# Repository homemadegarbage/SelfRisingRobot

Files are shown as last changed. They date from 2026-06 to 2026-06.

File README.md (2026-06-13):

# SelfRisingRobot

2軸サーボの起き上がりロボット "poco" です。

MuJoCo上で強化学習した起き上がり動作を、M5Atom搭載の実機ロボットで動かします。

詳細記事:

https://homemadegarbage.com/rl13

## Contents

- `3Dmodel/` - 実機ロボット用の3Dプリントモデル
- `RL/` - MuJoCoモデル、強化学習環境、学習済みPPOモデル
- `Arduino/` - M5Atom用スケッチとエクスポート済みポリシーネットワーク

各フォルダ内の詳しい使い方は、それぞれのREADMEを参照してください。

## 3D Model

`3Dmodel/` には実機製作用のSTLファイルを置いています。

- `footP.stl`
- `arm1P.stl`
- `arm2P.stl`
- `armhornP.stl`

## Reinforcement Learning

`RL/` にはシミュレーションと学習済みモデルを置いています。

主な内容:

- MuJoCoモデル
- Gymnasium環境
- Stable-Baselines3 PPOの学習済みモデル
- 再生・評価スクリプト

## Arduino

`Arduino/` には実機制御用のM5Atomスケッチを置いています。

主な内容:

- `robo03.ino`
- `policy_network.h`

`policy_network.h` は学習済みポリシーをCヘッダ化したもので、M5Atom上で起き上がり動作を実行するために使います。

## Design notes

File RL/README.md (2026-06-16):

# robo1 getup PPO

MuJoCo上の2自由度ロボット `robo1` が倒れた姿勢から起き上がるための学習済みPPOモデルです。

## Files

このリポジトリを動かすために必要なファイルは以下です。

- `robo1_getup_ppo.zip` - Stable-Baselines3 PPOの学習済みモデル
- `robo1_env.py` - Gymnasium/MuJoCo環境
- `robo1.xml` - MuJoCoモデル定義
- `assets/` - `robo1.xml`が参照するSTLメッシュ
- `play_robo1_policy.py` - 学習済みモデルの再生
- `eval_robo1_policy.py` - 各倒立姿勢からの評価
- `search_all_getup.py` - 各倒れ姿勢ごとの起き上がり軌道候補を探索し、`getup_reference.py` に反映するための `BEST_SEQ` を出力
- `getup_reference.py` - 教師データ生成に使う、各倒れ姿勢ごとのサーボ目標角waypoint列
- `scripted_getup.py` - `getup_reference.py` に定義した起き上がり軌道をMuJoCo viewerで再生確認
- `pretrain_robo1_from_scripted.py` - `getup_reference.py` の軌道から観測と教師actionのペアを生成し、PPO方策を事前学習
- `train_robo1.py` - PPOによる追加学習
- `export_policy_header.py` - 学習済みモデルからArduino用Cヘッダを生成
- `requirements.txt` - Python依存パッケージ

## Setup

```powershell
python -m venv .venv
.\.venv\Scripts\Activate.ps1
pip install -r requirements.txt
```

## Play

```powershell
python play_robo1_policy.py
```

特定の初期姿勢から再生する場合:

```powershell
python play_robo1_policy.py --pose roll_pos
python play_robo1_policy.py --pose roll_neg
python play_robo1_policy.py --pose pitch_pos
python play_robo1_policy.py --pose pitch_neg
```

## Evaluate

```powershell
python eval_robo1_policy.py
```

## Training

`getup_reference.py` に定義した起き上がり教師データから初期方策を事前学習します。

起き上がり軌道を再探索する場合は、以下を実行します。

```powershell
python search_all_getup.py
```
出力された `BEST_SEQ` または `REFERENCE_CANDIDATES` の配列を
`getup_reference.py` の `getup_sequence_for_pose()` に反映します。

教師データから初期方策を事前学習

```powershell
python pretrain_robo1_from_scripted.py
```

これにより `robo1_getup_ppo.zip` が生成されます。

続けてPPOで追加学習します。

```powershell
python train_robo1.py --model-in robo1_getup_ppo.zip --timesteps 200000 --n-envs 6 --model-out robo1_getup_ppo
```

ゼロからPPO学習する場合は `--model-in` を省略します。

```powershell
python train_robo1.py --timesteps 200000 --n-envs 6 --model-out robo1_getup_ppo
```

## Export for Arduino

学習済みモデルから `policy_network.h` を生成します。

```powershell
python export_policy_header.py robo1_getup_ppo.zip -o policy_network.h
```

生成した `policy_network.h` をArduinoスケッチ側に配置して使用します。

## Notes

- `robo1_getup_ppo.zip`は`robo1.xml`と`robo1_env.py`の環境定義に依存しています。
- `assets/`内のSTLファイルがないとMuJoCoモデルを読み込めません。
- 実行はリポジトリ直下で行ってください。

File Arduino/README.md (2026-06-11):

# robo03

M5Atomで2自由度ロボットを制御し、学習済みポリシーで起き上がり動作を行うArduinoスケッチです。

## Files

- `robo03/robo03.ino` - M5Atom用の制御スケッチ
- `robo03/policy_network.h` - 学習済みポリシーをCヘッダ化したもの

`policy_network.h` は `robo03.ino` から読み込まれるため、必ず同じ `robo03` フォルダ内に置いてください。

## Required Libraries

Arduino IDEのライブラリマネージャなどで以下を入れてください。

- M5Atom
- Kalman
- ESP32Servo

ESP32ボード環境も必要です。

## Upload

Arduino IDEで `robo03/robo03.ino` を開き、M5Atom向けにビルドして書き込んでください。

## Wi-Fi Control

起動するとM5AtomがWi-Fiアクセスポイントを作成します。

- SSID: `robo1`
- Password: `password`
- URL: `http://192.168.42.1`

ブラウザからアクセスすると、サーボの手動調整、起き上がり開始/停止、自動起き上がりのON/OFFを操作できます。

## Button

M5Atom本体ボタンでも起き上がり動作を開始できます。

起き上がり中にボタンを押すと、起き上がり動作を停止して手動モードに戻ります。

## Notes

- サーボ1はGPIO 26、サーボ2はGPIO 32に接続する想定です。
- サーボのオフセットとパルス幅はWeb画面から調整でき、Preferencesに保存されます。
- `policy_network.h` は生成済みのポリシーネットワークです。別の学習結果を使う場合は、このファイルを差し替えてください。

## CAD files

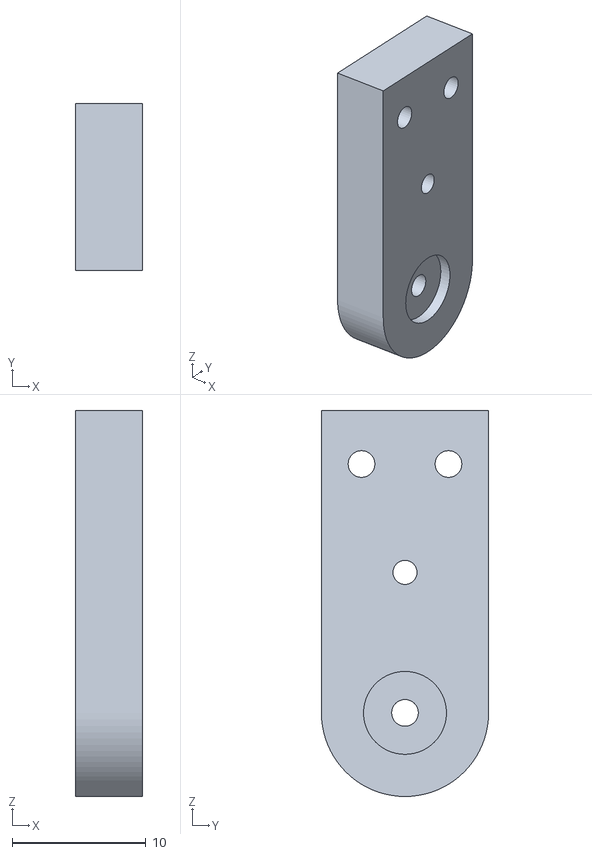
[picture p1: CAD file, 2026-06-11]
3Dmodel/armhornP.stl
5.00 x 12.5 x 28.9

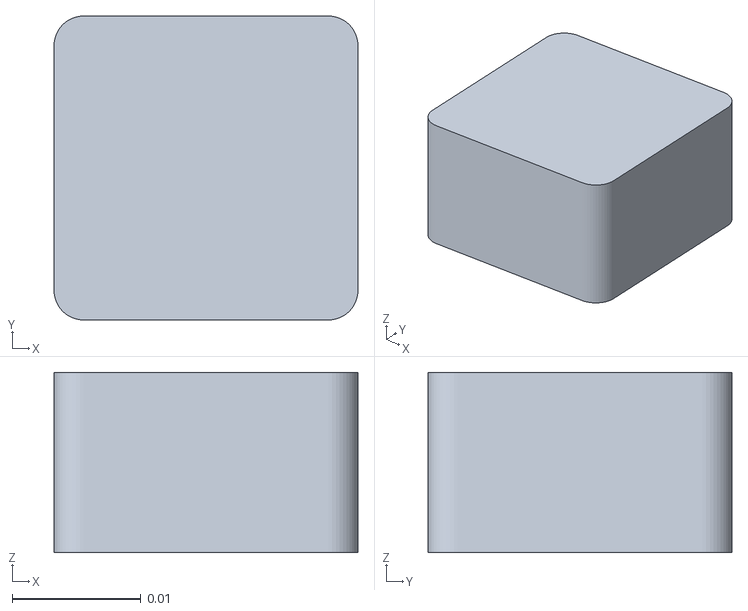
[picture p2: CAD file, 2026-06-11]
RL/assets/ATOM.stl
0.0236 x 0.0236 x 0.014

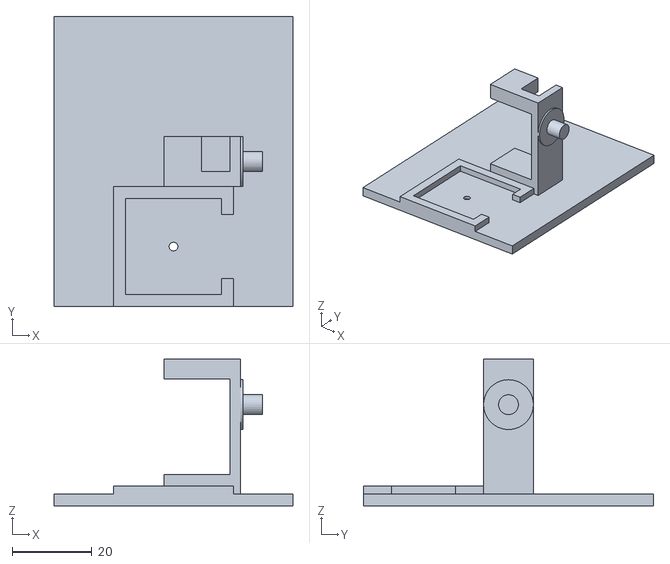
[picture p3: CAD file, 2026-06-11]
3Dmodel/footP.stl
60.0 x 72.9 x 36.8

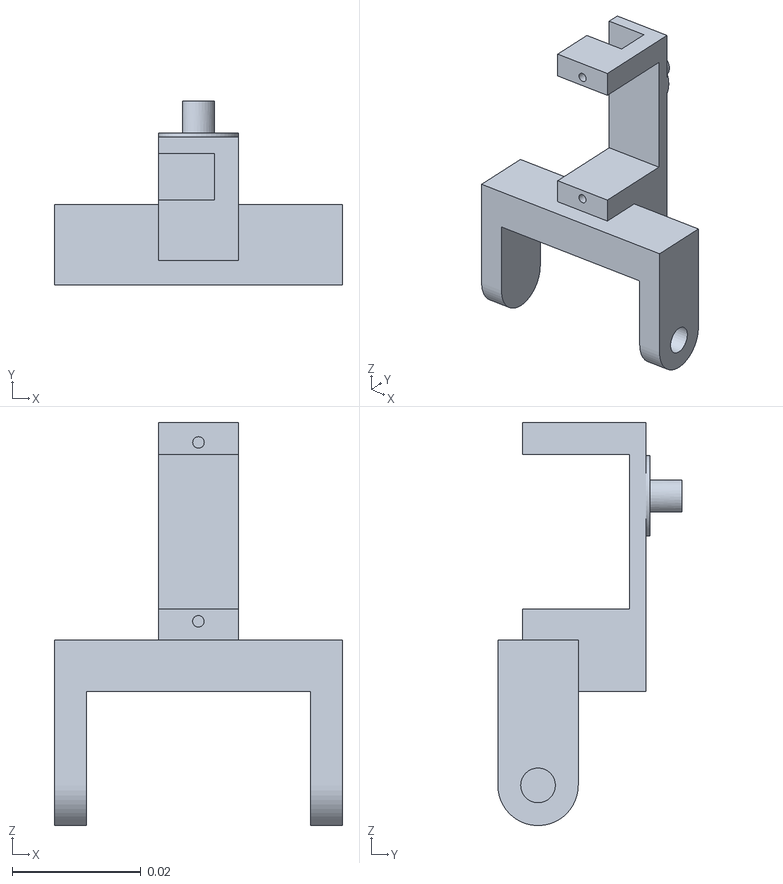
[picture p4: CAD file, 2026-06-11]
RL/assets/arm1.stl
0.0448 x 0.0287 x 0.0626

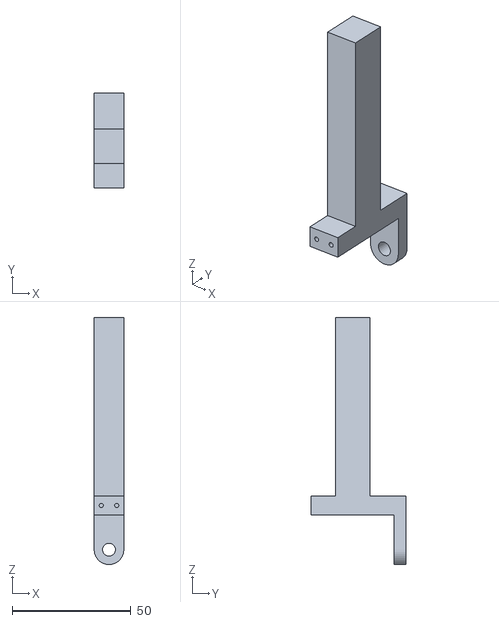
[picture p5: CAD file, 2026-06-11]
3Dmodel/arm2P.stl
12.5 x 39.8 x 103.8

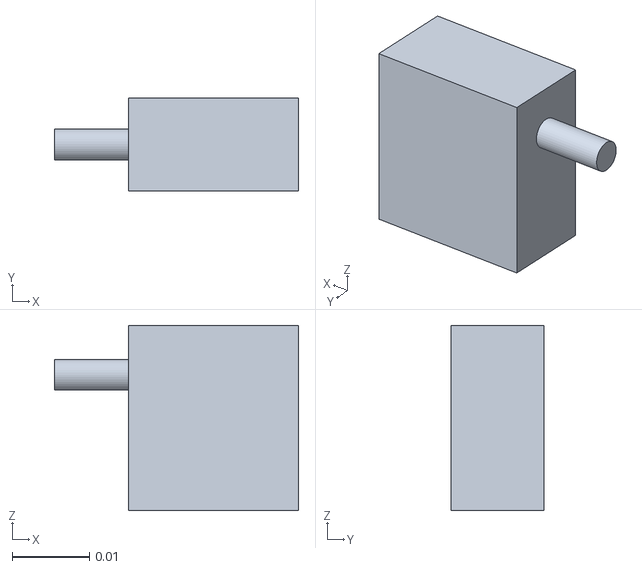
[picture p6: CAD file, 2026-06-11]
RL/assets/servo1.stl
0.0316 x 0.012 x 0.024

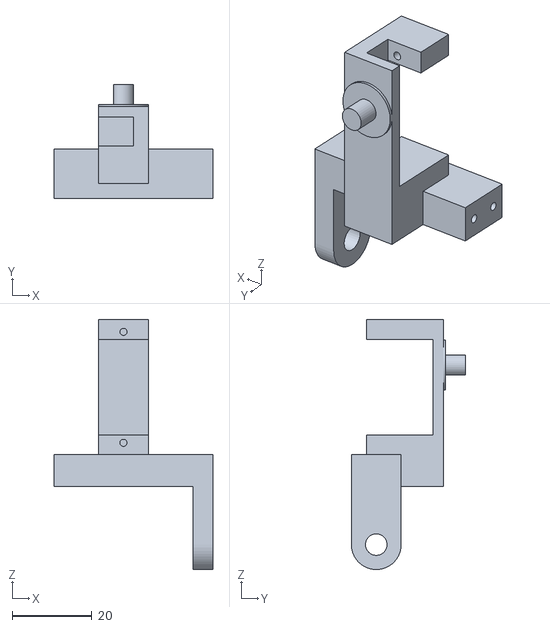
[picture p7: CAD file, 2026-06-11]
3Dmodel/arm1P.stl
39.8 x 28.7 x 62.6

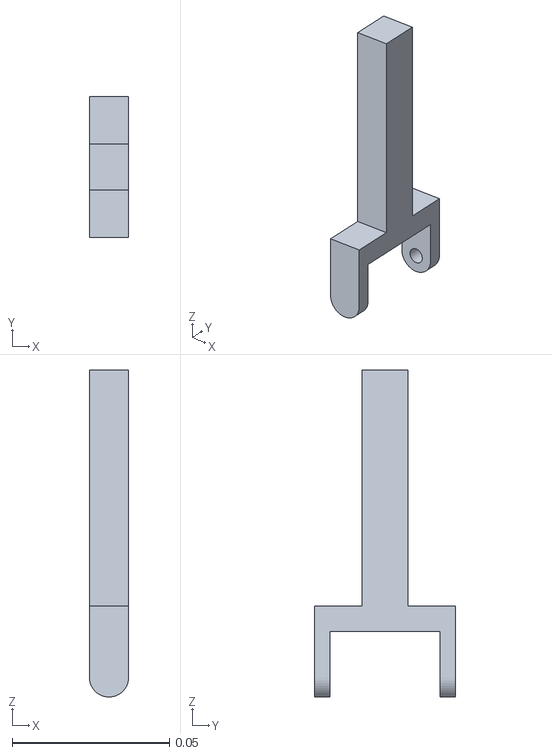
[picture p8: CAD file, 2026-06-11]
RL/assets/arm2.stl
0.0125 x 0.0448 x 0.104

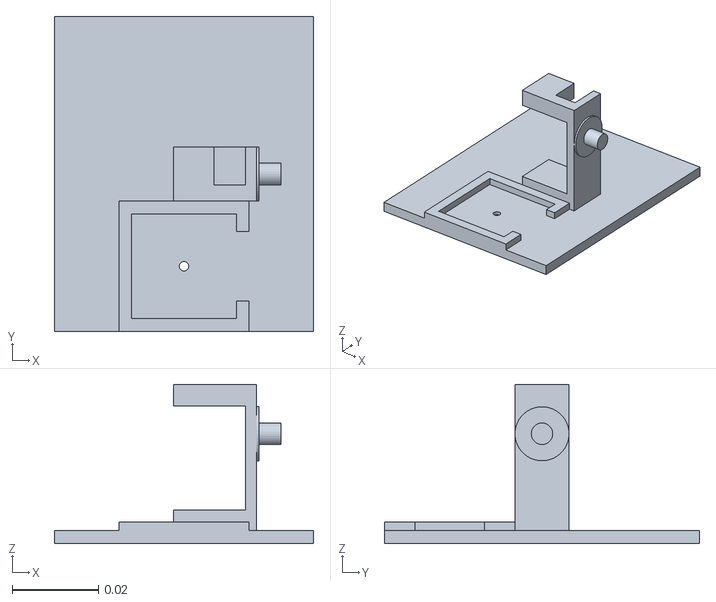
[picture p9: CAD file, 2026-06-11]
RL/assets/foot.stl
0.06 x 0.0729 x 0.0368

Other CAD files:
RL/assets/servo2.stl

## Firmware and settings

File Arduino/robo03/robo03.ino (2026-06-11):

#include <M5Atom.h>
#include <Kalman.h>
#include <WiFi.h>
#include <WebServer.h>
#include <Preferences.h>
#include <ESP32Servo.h>
#include <math.h>
#include "policy_network.h"

WebServer server(80);

const char ssid[] = "robo1";
const char pass[] = "password";

const IPAddress ip(192,168,42,1);
const IPAddress subnet(255,255,255,0);

Servo servo1, servo2;

int ang1 = 0, offset1 = 0, pulse1 = 1000;
int ang2 = 0, offset2 = 0, pulse2 = 1000;

float pitch, roll;
float servo1_target = 0.0f, servo2_target = 0.0f;

float accX = 0, accY = 0, accZ = 0;
float gyroX = 0, gyroY = 0, gyroZ = 0;
float theta_X = 0.0, theta_Y = 0.0;
float kalAngleX, kalAngleDotX, kalAngleY, kalAngleDotY;
Kalman kalmanX, kalmanY;


unsigned long oldTime = 0, loopTime, nowTime;
float dt;


Preferences preferences;

enum RobotMode {
  MODE_MANUAL,
  MODE_GETUP,
  MODE_GETUP_DONE,
  MODE_GETUP_ABORT,
};

volatile RobotMode robotMode = MODE_MANUAL;
volatile bool autoGetupEnabled = true;

const float TARGET_DELTA_RAD = 0.08f;
const float TARGET_LIMIT_RAD = 1.55f;
const unsigned long GETUP_PERIOD_US = 20000;
const unsigned long GETUP_TIMEOUT_MS = 14000;
const float GETUP_DONE_TILT_RAD = 0.25f;
const unsigned long GETUP_DONE_HOLD_MS = 700;
const float AUTO_FALL_TILT_RAD = 0.75f;
const unsigned long AUTO_FALL_HOLD_MS = 300;
const unsigned long AUTO_RESTART_COOLDOWN_MS = 1500;

unsigned long lastPolicyUs = 0;
unsigned long getupStartMs = 0;
unsigned long uprightStartMs = 0;
unsigned long fallStartMs = 0;
unsigned long lastGetupEndMs = 0;

float clampf(float x, float lo, float hi) {
  if (x < lo) return lo;
  if (x > hi) return hi;
  return x;
}

void writeServoTargetsRad(float target1, float target2) {
  int deg1 = (int)roundf(target1 * RAD_TO_DEG);
  int deg2 = (int)roundf(target2 * RAD_TO_DEG);
  deg1 = (int)clampf(deg1, -90, 90);
  deg2 = (int)clampf(deg2, -90, 90);

  servo1.write(-deg1 + 90);
  servo2.write(-deg2 + 90);
}

void startGetupMode() {
  noInterrupts();
  autoGetupEnabled = true;
  servo1_target = 0.0f;
  servo2_target = 0.0f;
  robotMode = MODE_GETUP;
  interrupts();

  getupStartMs = millis();
  uprightStartMs = 0;
  lastPolicyUs = 0;
  writeServoTargetsRad(servo1_target, servo2_target);
}

void stopGetupMode(RobotMode nextMode = MODE_MANUAL) {
  noInterrupts();
  robotMode = nextMode;
  interrupts();
  lastGetupEndMs = millis();
  fallStartMs = 0;
}

const char *modeName() {
  switch (robotMode) {
    case MODE_GETUP: return "GETUP";
    case MODE_GETUP_DONE: return "DONE";
    case MODE_GETUP_ABORT: return "ABORT";
    default: return "MANUAL";
  }
}

void updateAutoGetup() {
  if (!autoGetupEnabled || robotMode == MODE_GETUP) {
    fallStartMs = 0;
    return;
  }

  unsigned long nowMs = millis();
  if (nowMs - lastGetupEndMs < AUTO_RESTART_COOLDOWN_MS) {
    fallStartMs = 0;
    return;
  }

  bool fallen = fabsf(roll) > AUTO_FALL_TILT_RAD || fabsf(pitch) > AUTO_FALL_TILT_RAD;
  if (!fallen) {
    fallStartMs = 0;
    if (robotMode == MODE_GETUP_DONE || robotMode == MODE_GETUP_ABORT) {
      robotMode = MODE_MANUAL;
    }
    return;
  }

  if (fallStartMs == 0) fallStartMs = nowMs;
  if (nowMs - fallStartMs > AUTO_FALL_HOLD_MS) {
    startGetupMode();
  }
}

void runGetupPolicy() {
  unsigned long nowUs = micros();
  if (lastPolicyUs != 0 && nowUs - lastPolicyUs < GETUP_PERIOD_US) {
    return;
  }
  lastPolicyUs = nowUs;

  float obs[OBS_DIM] = {
    roll,
    pitch,
    servo1_target,
    servo2_target,
  };
  float action[ACTION_DIM];
  forward_policy(obs, action);

  action[0] = clampf(action[0], -1.0f, 1.0f);
  action[1] = clampf(action[1], -1.0f, 1.0f);

  servo1_target = clampf(servo1_target + action[0] * TARGET_DELTA_RAD,
                         -TARGET_LIMIT_RAD, TARGET_LIMIT_RAD);
  servo2_target = clampf(servo2_target + action[1] * TARGET_DELTA_RAD,
                         -TARGET_LIMIT_RAD, TARGET_LIMIT_RAD);

  writeServoTargetsRad(servo1_target, servo2_target);

  unsigned long nowMs = millis();
  bool upright = fabsf(roll) < GETUP_DONE_TILT_RAD && fabsf(pitch) < GETUP_DONE_TILT_RAD;
  if (upright) {
    if (uprightStartMs == 0) uprightStartMs = nowMs;
    if (nowMs - uprightStartMs > GETUP_DONE_HOLD_MS) {
      stopGetupMode(MODE_GETUP_DONE);
    }
  } else {
    uprightStartMs = 0;
  }

  if (nowMs - getupStartMs > GETUP_TIMEOUT_MS) {
    stopGetupMode(MODE_GETUP_ABORT);
  }
}


// =================================
//   IMU
// =================================
void get_theta(){
  M5.IMU.getAccelData(&accX,&accY,&accZ);
  theta_X  = atan2(accY, sqrt(accX * accX + accZ * accZ)) * RAD_TO_DEG;
  theta_Y  = -atan2(-accX, -accZ) * RAD_TO_DEG;
}

void get_gyro(){
  M5.IMU.getGyroData(&gyroX,&gyroY,&gyroZ);
  gyroX = -gyroX;
}


//ブラウザ表示
void handleRoot() {
  String temp ="<!DOCTYPE html> \n<html lang=\"ja\">";
  temp +="<head>";
  temp +="<meta charset=\"utf-8\">";
  temp +="<title>XL330-pend</title>";
  temp +="<meta name=\"viewport\" content=\"width=device-width, initial-scale=1\">";
  temp +="<style>";
  temp +=".container{";
  temp +="  max-width: 500px;";
  temp +="  margin: auto;";
  temp +="  text-align: center;";
  temp +="  font-size: 1.2rem;";
  temp +="}";
  temp +="span,.pm{";
  temp +="  display: inline-block;";
  temp +="  border: 1px solid #ccc;";
  temp +="  width: 50px;";
  temp +="  height: 30px;";
  temp +="  vertical-align: middle;";
  temp +="  margin-bottom: 20px;";
  temp +="}";
  temp +="span{";
  temp +="  width: 120px;";
  temp +="}";
  temp +="button{";
  temp +="  width: 100px;";
  temp +="  height: 40px;";
  temp +="  font-weight: bold;";
  temp +="  margin-bottom: 20px;";
  temp +="}";
  temp +="button.on{ background:lime; color:white; }";
  temp +=".column-3{ max-width:330px; margin:auto; text-align:center; display:flex; justify-content:space-between; flex-wrap:wrap; }";
  temp +="</style>";
  temp +="</head>";
  
  temp +="<body>";
  temp +="<div class=\"container\">";

  temp +="mode<br>";
  temp +="<span>" + String(modeName()) + "</span><br>";
  temp +="<a href=\"/getupStart\"><button class=\"on\">GETUP</button></a>";
  temp +="<a href=\"/getupStop\"><button>STOP</button></a><br>";
  temp +="auto getup<br>";
  temp +="<span>" + String(autoGetupEnabled ? "ON" : "OFF") + "</span><br>";
  temp +="<a href=\"/autoOn\"><button class=\"on\">AUTO ON</button></a>";
  temp +="<a href=\"/autoOff\"><button>AUTO OFF</button></a><br>";
  temp +="roll/pitch rad<br>";
  temp +="<span>" + String(roll, 3) + "</span>";
  temp +="<span>" + String(pitch, 3) + "</span><br>";
  temp +="target rad<br>";
  temp +="<span>" + String(servo1_target, 3) + "</span>";
  temp +="<span>" + String(servo2_target, 3) + "</span><br>";

  
  //ang1
  temp +="ang1<br>";
  temp +="<a class=\"pm\" href=\"/ang1M\">-</a>";
  temp +="<span>" + String(ang1) + "</span>";
  temp +="<a class=\"pm\" href=\"/ang1P\">+</a><br>";

  //offset1
  temp +="offset1<br>";
  temp +="<a class=\"pm\" href=\"/offset1M\">-</a>";
  temp +="<span>" + String(offset1) + "</span>";
  temp +="<a class=\"pm\" href=\"/offset1P\">+</a><br>";

  //pulse1
  temp +="pulse1<br>";
  temp +="<a class=\"pm\" href=\"/pulse1M\">-</a>";
  temp +="<span>" + String(pulse1) + "</span>";
  temp +="<a class=\"pm\" href=\"/pulse1P\">+</a><br>";

  //ang2
  temp +="ang2<br>";
  temp +="<a class=\"pm\" href=\"/ang2M\">-</a>";
  temp +="<span>" + String(ang2) + "</span>";
  temp +="<a class=\"pm\" href=\"/ang2P\">+</a><br>";

  //offset2
  temp +="offset2<br>";
  temp +="<a class=\"pm\" href=\"/offset2M\">-</a>";
  temp +="<span>" + String(offset2) + "</span>";
  temp +="<a class=\"pm\" href=\"/offset2P\">+</a><br>";

  //pulse2
  temp +="pulse2<br>";
  temp +="<a class=\"pm\" href=\"/pulse2M\">-</a>";
  temp +="<span>" + String(pulse2) + "</span>";
  temp +="<a class=\"pm\" href=\"/pulse2P\">+</a><br>";

  temp +="</div>";
  temp +="</body>";
  server.send(200, "text/HTML", temp);
}


void ang1M() {
  if(ang1 >= -90){
    ang1 -= 5;
  }
  handleRoot();
}
void ang1P() {
  if(ang1 <= 90){
    ang1 += 5;
  }
  handleRoot();
}

void offset1M() {
  if(offset1 >= -300){
    offset1 -= 2;
    preferences.putInt("offset1", offset1);
    servo1.detach();
    servo1.attach(26, 1500 + offset1 - pulse1, 1500 + offset1 + pulse1);
  }
  handleRoot();
}
void offset1P() {
  if(offset1 <= 300){
    offset1 += 2;
    preferences.putInt("offset1", offset1);
    servo1.detach();
    servo1.attach(26, 1500 + offset1 - pulse1, 1500 + offset1 + pulse1);
  }
  handleRoot();
}

void pulse1M() {
  if(pulse1 > 0){
    pulse1 -= 20;
    preferences.putInt("pulse1", pulse1);
    servo1.detach();
    servo1.attach(26, 1500 + offset1 - pulse1, 1500 + offset1 + pulse1);
  }
  handleRoot();
}
void pulse1P() {
  if(pulse1 <= 1200){
    pulse1 += 20;
    preferences.putInt("pulse1", pulse1);
    servo1.detach();
    servo1.attach(26, 1500 + offset1 - pulse1, 1500 + offset1 + pulse1);
  }
  handleRoot();
}



void ang2M() {
  if(ang2 >= -90){
    ang2 -= 5;
  }
  handleRoot();
}
void ang2P() {
  if(ang2 <= 90){
    ang2 += 5;
  }
  handleRoot();
}

void offset2M() {
  if(offset2 >= -300){
    offset2 -= 2;
    preferences.putInt("offset2", offset2);
    servo2.detach();
    servo2.attach(32, 1500 + offset2 - pulse2, 1500 + offset2 + pulse2);
  }
  handleRoot();
}
void offset2P() {
  if(offset2 <= 300){
    offset2 += 2;
    preferences.putInt("offset2", offset2);
    servo2.detach();
    servo2.attach(32, 1500 + offset2 - pulse2, 1500 + offset2 + pulse2);
  }
  handleRoot();
}

void pulse2M() {
  if(pulse2 > 0){
    pulse2 -= 20;
    preferences.putInt("pulse2", pulse2);
    servo2.detach();
    servo2.attach(32, 1500 + offset2 - pulse2, 1500 + offset2 + pulse2);
  }
  handleRoot();
}
void pulse2P() {
  if(pulse2 <= 1200){
    pulse2 += 20;
    preferences.putInt("pulse2", pulse2);
    servo2.detach();
    servo2.attach(32, 1500 + offset2 - pulse2, 1500 + offset2 + pulse2);
  }
  handleRoot();
}

void getupStart() {
  startGetupMode();
  handleRoot();
}

void getupStop() {
  autoGetupEnabled = false;
  stopGetupMode(MODE_MANUAL);
  handleRoot();
}

void autoOn() {
  autoGetupEnabled = true;
  stopGetupMode(MODE_MANUAL);
  handleRoot();
}

void autoOff() {
  autoGetupEnabled = false;
  stopGetupMode(MODE_MANUAL);
  handleRoot();
}


// =================================
// Core0
// =================================
void core0(void *){
  WiFi.softAP(ssid,pass);
  delay(100);
  WiFi.softAPConfig(ip,ip,subnet);

  server.on("/", handleRoot); 

  server.on("/ang1P", ang1P);
  server.on("/ang1M", ang1M);
  server.on("/offset1P", offset1P);
  server.on("/offset1M", offset1M);
  server.on("/pulse1P", pulse1P);
  server.on("/pulse1M", pulse1M);

  server.on("/ang2P", ang2P);
  server.on("/ang2M", ang2M);
  server.on("/offset2P", offset2P);
  server.on("/offset2M", offset2M);
  server.on("/pulse2P", pulse2P);
  server.on("/pulse2M", pulse2M);

  server.on("/getupStart", getupStart);
  server.on("/getupStop", getupStop);
  server.on("/autoOn", autoOn);
  server.on("/autoOff", autoOff);
  
  server.begin();

  for(;;){
    server.handleClient();

    
    disableCore0WDT();
  }
}

// =================================
// Setup
// =================================
void setup(){
  M5.begin(true, false, true); //SerialEnable, bool I2CEnable, DisplayEnable
  

  preferences.begin("parameter",false);

  offset1 = preferences.getInt("offset1", offset1);
  pulse1 = preferences.getInt("pulse1", pulse1);

  offset2 = preferences.getInt("offset2", offset2);
  pulse2 = preferences.getInt("pulse2", pulse2);


  M5.IMU.Init();

  //フルスケールレンジ
  M5.IMU.SetAccelFsr(M5.IMU.AFS_2G);
  M5.IMU.SetGyroFsr(M5.IMU.GFS_250DPS);

  get_theta();
  kalmanX.setAngle(theta_X);
  kalmanY.setAngle(theta_Y);

  servo1.setPeriodHertz(50);
  servo1.attach(26, 1500 + offset1 - pulse1, 1500 + offset1 + pulse1);
  servo2.setPeriodHertz(50);
  servo2.attach(32, 1500 + offset2 - pulse2, 1500 + offset2 + pulse2);

  // Core0 start
  xTaskCreatePinnedToCore(core0,"core0",4096,NULL,1,NULL,0);

  delay(500);
  oldTime = micros();
}

// =================================
// LOOP (制御)
// =================================
void loop(){
  M5.update();

  nowTime = micros();
  loopTime = nowTime - oldTime;
  oldTime = nowTime;
  dt = (float)loopTime / 1000000.0; //sec

  get_theta();
  get_gyro();
    
  kalAngleX = kalmanX.getAngle(theta_X, gyroX, dt);
  kalAngleY = kalmanY.getAngle(theta_Y, gyroY, dt);
  
  kalAngleDotX = kalmanX.getRate();
  kalAngleDotY = kalmanY.getRate();

  pitch = kalAngleX * DEG_TO_RAD;
  roll = -kalAngleY * DEG_TO_RAD;

  if (M5.Btn.wasPressed()) {
    if (robotMode == MODE_GETUP) {
      autoGetupEnabled = false;
      stopGetupMode(MODE_MANUAL);
    } else {
      startGetupMode();
    }
  }

  updateAutoGetup();

  /*
  Serial.print(modeName());
  Serial.print(", ");
  Serial.print(pitch);
  Serial.print(", ");
  Serial.print(roll);
  Serial.print(", ");
  Serial.print(servo1_target);
  Serial.print(", ");
  Serial.println(servo2_target);
  */

  if (robotMode == MODE_GETUP) {
    runGetupPolicy();
    delay(1);
  } else {
    servo1.write(-ang1 + 90);
    servo2.write(-ang2 + 90);
    delay(10);
  }

}

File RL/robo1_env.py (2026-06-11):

import math
from pathlib import Path

import gymnasium as gym
import mujoco
import numpy as np
from gymnasium import spaces


FALLEN_POSES = {
    "roll_pos": (math.pi / 2.0, 0.0),
    "roll_neg": (-math.pi / 2.0, 0.0),
    "pitch_pos": (0.0, math.pi / 2.0),
    "pitch_neg": (0.0, -math.pi / 2.0),
}
DEFAULT_FALLEN_POSES = tuple(FALLEN_POSES.keys())


def roll_pitch_to_quat(roll, pitch):
    cr = math.cos(roll / 2.0)
    sr = math.sin(roll / 2.0)
    cp = math.cos(pitch / 2.0)
    sp = math.sin(pitch / 2.0)
    return np.array([cr * cp, sr * cp, cr * sp, -sr * sp], dtype=np.float64)


def quat_to_roll_pitch(q):
    w, x, y, z = q
    sinr_cosp = 2.0 * (w * x + y * z)
    cosr_cosp = 1.0 - 2.0 * (x * x + y * y)
    roll = math.atan2(sinr_cosp, cosr_cosp)

    sinp = 2.0 * (w * y - z * x)
    sinp = max(-1.0, min(1.0, sinp))
    pitch = math.asin(sinp)
    return roll, pitch


class Robo1GetupEnv(gym.Env):
    metadata = {"render_modes": []}

    def __init__(self, xml_path="robo1.xml", fallen_poses=None):
        super().__init__()
        self.model = mujoco.MjModel.from_xml_path(str(Path(xml_path)))
        self.data = mujoco.MjData(self.model)

        self.frame_skip = 20
        self.max_steps = 700
        self.target_delta = 0.08
        self.target_limit = 1.55
        self.settle_steps = 200
        self.fallen_poses = list(fallen_poses or DEFAULT_FALLEN_POSES)
        self.current_pose_name = self.fallen_poses[0]

        self.foot_body_id = mujoco.mj_name2id(
            self.model, mujoco.mjtObj.mjOBJ_BODY, "foot"
        )
        self.servo1_qpos_id = self.model.jnt_qposadr[
            mujoco.mj_name2id(self.model, mujoco.mjtObj.mjOBJ_JOINT, "servo1_joint")
        ]
        self.servo2_qpos_id = self.model.jnt_qposadr[
            mujoco.mj_name2id(self.model, mujoco.mjtObj.mjOBJ_JOINT, "servo2_joint")
        ]
        self.servo1_qvel_id = self.model.jnt_dofadr[
            mujoco.mj_name2id(self.model, mujoco.mjtObj.mjOBJ_JOINT, "servo1_joint")
        ]
        self.servo2_qvel_id = self.model.jnt_dofadr[
            mujoco.mj_name2id(self.model, mujoco.mjtObj.mjOBJ_JOINT, "servo2_joint")
        ]
        self.standing_height = self._compute_standing_height()

        self.action_space = spaces.Box(-1.0, 1.0, shape=(2,), dtype=np.float32)
        self.observation_space = spaces.Box(
            low=np.array(
                [-math.pi, -math.pi, -1.55, -1.55],
                dtype=np.float32,
            ),
            high=np.array(
                [math.pi, math.pi, 1.55, 1.55],
                dtype=np.float32,
            ),
            dtype=np.float32,
        )

        self.step_count = 0
        self.target = np.zeros(2, dtype=np.float64)
        self.success_count = 0
        self.prev_upright = 0.0

    def _compute_standing_height(self):
        data = mujoco.MjData(self.model)
        data.qpos[:] = 0.0
        data.qvel[:] = 0.0
        data.qpos[0:3] = [0.0, 0.0, 0.08]
        data.qpos[3:7] = [1.0, 0.0, 0.0, 0.0]
        data.qpos[self.servo1_qpos_id] = 0.0
        data.qpos[self.servo2_qpos_id] = 0.0
        data.ctrl[:] = 0.0
        mujoco.mj_forward(self.model, data)

        for _ in range(self.settle_steps):
            data.ctrl[:] = 0.0
            mujoco.mj_step(self.model, data)

        return float(data.xpos[self.foot_body_id, 2])

    def _set_fixed_fallen_pose(self, pose_name=None):
        self.data.qpos[:] = 0.0
        self.data.qvel[:] = 0.0

        self.data.qpos[0:3] = [0.0, 0.0, 0.08]
        self.current_pose_name = pose_name or self.current_pose_name
        roll, pitch = FALLEN_POSES[self.current_pose_name]
        self.data.qpos[3:7] = roll_pitch_to_quat(roll, pitch)
        self.data.qpos[self.servo1_qpos_id] = 0.0
        self.data.qpos[self.servo2_qpos_id] = 0.0

        self.target[:] = 0.0
        self.data.ctrl[:] = self.target
        mujoco.mj_forward(self.model, self.data)

        for _ in range(self.settle_steps):
            self.data.ctrl[:] = self.target
            mujoco.mj_step(self.model, self.data)

        self.target[:] = 0.0
        self.data.ctrl[:] = self.target

    def _get_obs(self):
        roll, pitch = quat_to_roll_pitch(self.data.qpos[3:7])
        return np.array(
            [
                roll,
                pitch,
                self.target[0],
                self.target[1],
            ],
            dtype=np.float32,
        )

    def _upright(self):
        xmat = self.data.xmat[self.foot_body_id].reshape(3, 3)
        return float(xmat[2, 2])

    def _foot_height(self):
        return float(self.data.xpos[self.foot_body_id, 2])

    def _servo_angles(self):
        return np.array(
            [
                self.data.qpos[self.servo1_qpos_id],
                self.data.qpos[self.servo2_qpos_id],
            ],
            dtype=np.float64,
        )

    def _servo_velocities(self):
        return np.array(
            [
                self.data.qvel[self.servo1_qvel_id],
                self.data.qvel[self.servo2_qvel_id],
            ],
            dtype=np.float64,
        )

    def reset(self, seed=None, options=None):
        super().reset(seed=seed)
        self.step_count = 0
        self.success_count = 0
        pose_name = None
        if options is not None:
            pose_name = options.get("pose")
        if pose_name is None:
            pose_name = self.np_random.choice(self.fallen_poses)
        self._set_fixed_fallen_pose(pose_name)
        self.prev_upright = self._upright()
        return self._get_obs(), {"pose": self.current_pose_name}

    def step(self, action):
        action = np.asarray(action, dtype=np.float64)
        action = np.clip(action, -1.0, 1.0)

        old_target = self.target.copy()
        self.target += action * self.target_delta
        self.target = np.clip(self.target, -self.target_limit, self.target_limit)

        for _ in range(self.frame_skip):
            self.data.ctrl[:] = self.target
            mujoco.mj_step(self.model, self.data)

        self.step_count += 1
        obs = self._get_obs()

        upright = self._upright()
        upright_progress = upright - self.prev_upright
        self.prev_upright = upright
        roll, pitch = float(obs[0]), float(obs[1])
        servo_angles = self._servo_angles()
        servo_velocities = self._servo_velocities()
        foot_height_error = self._foot_height() - self.standing_height
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
